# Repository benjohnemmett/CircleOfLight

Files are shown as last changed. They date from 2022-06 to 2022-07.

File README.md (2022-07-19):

# CircleOfLight
Hardware &amp; firmware files for a simple PCB light game.

The hardware files are a PCB design which includes 12 LED lights in a circle and 3 push buttons. It is driven by an atmega328p.

The firmware is a multimode setup with a main menu and up to 12 programs. Currently only 3 programs are implemented: Reflex Game, Countdown Timer, and Hardware Test.

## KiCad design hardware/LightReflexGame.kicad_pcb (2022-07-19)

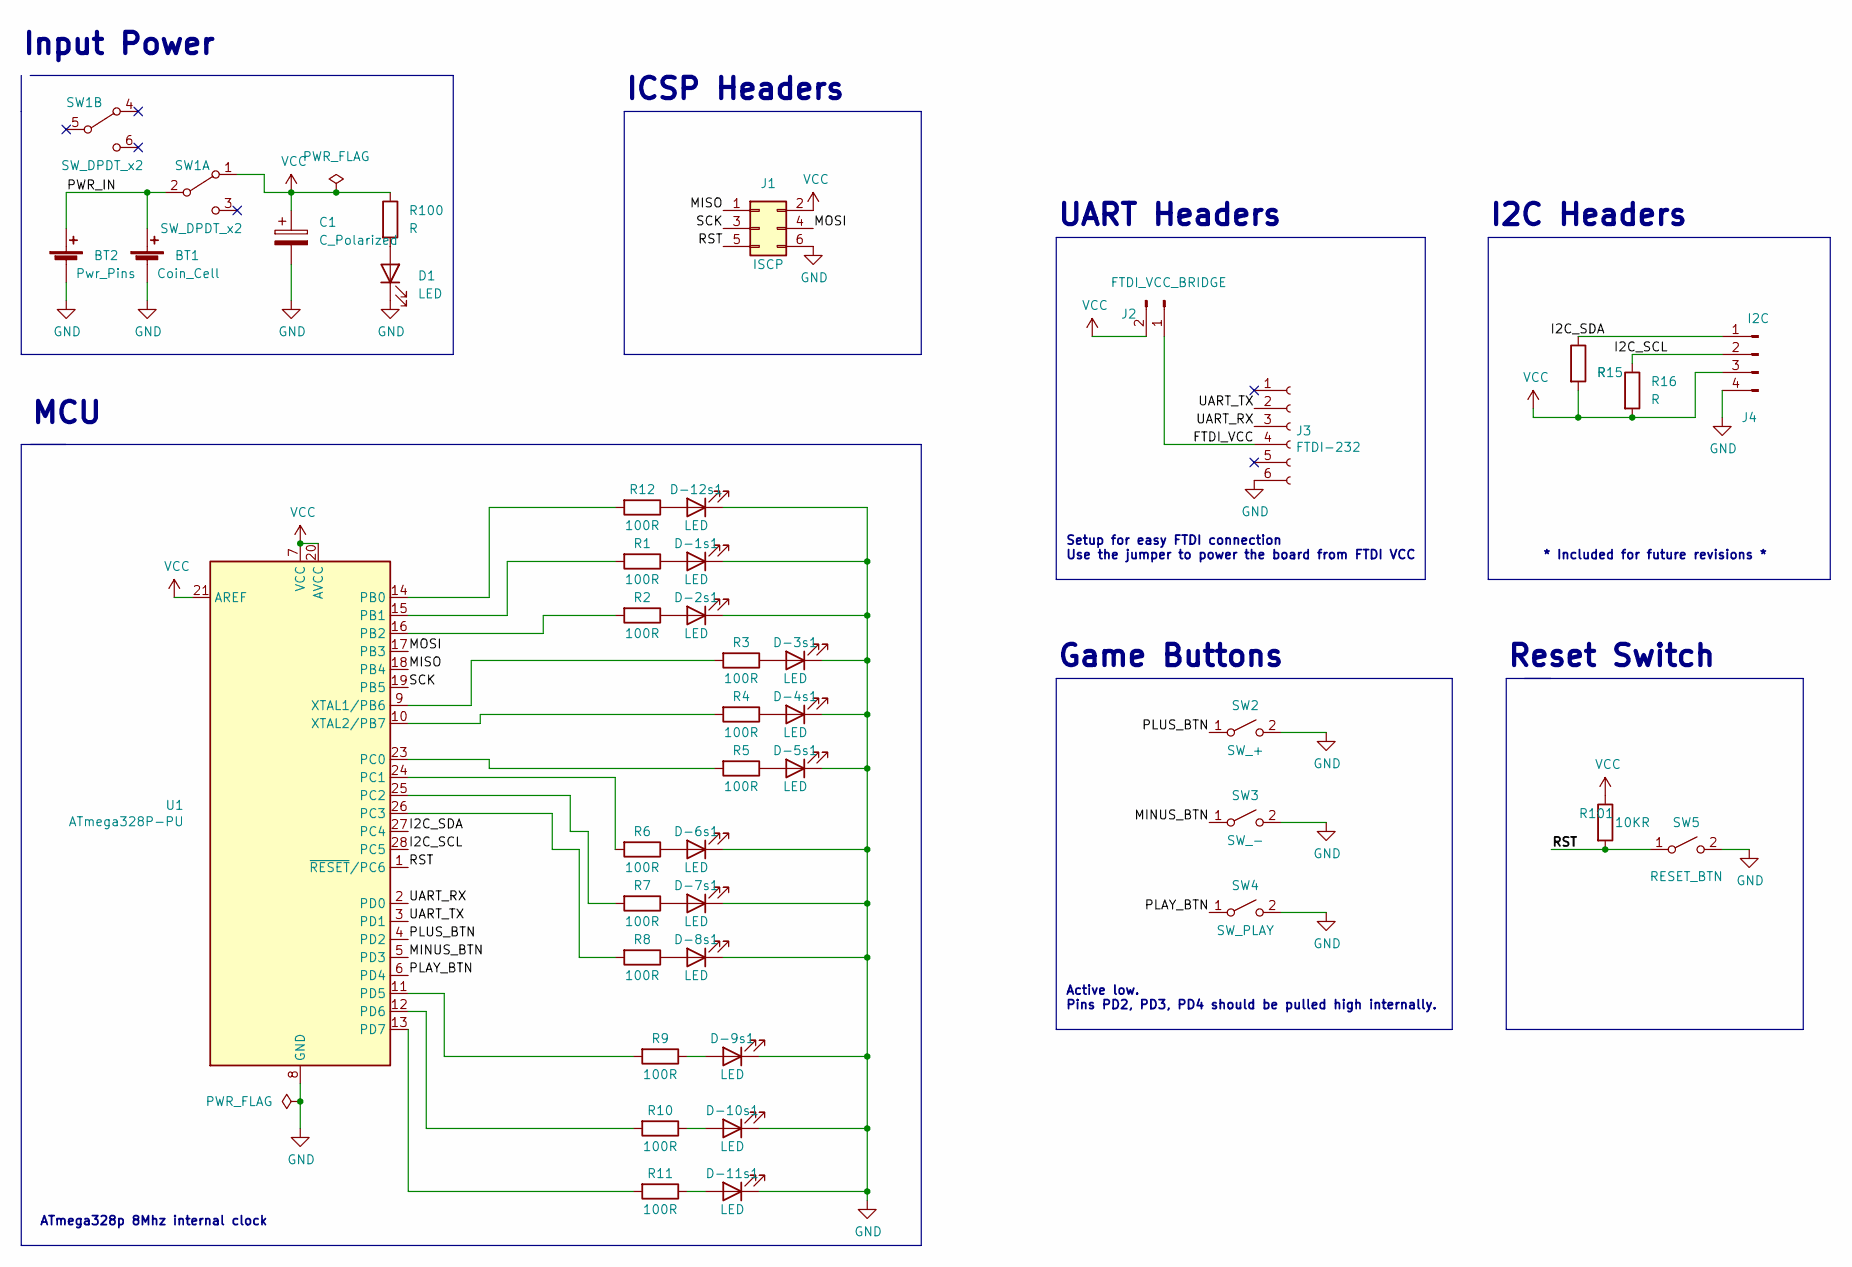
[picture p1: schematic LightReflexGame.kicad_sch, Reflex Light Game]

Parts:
BT1: Coin_Cell; BatteryHolder_bje_THT_1x2032
BT2: Pwr_Pins; PinHeader_1x02_P2.54mm_Vertical
C1: C_Polarized; CP_EIA-3528-12_Kemet-T
D1: LED; LED_0805_2012Metric
D-1s1, D-2s1, D-3s1, D-4s1, D-5s1, D-6s1, D-7s1, D-8s1, D-9s1, D-10s1, D-11s1, D-12s1: LED; LED_0805_2012Metric_Pad1.15x1.40mm_HandSolder
J1: ISCP; PinHeader_2x03_P2.54mm_Vertical
J2: FTDI_VCC_BRIDGE; PinHeader_1x02_P2.54mm_Vertical
J3: FTDI-232; PinHeader_1x06_P2.54mm_Vertical
J4: I2C; PinHeader_1x04_P2.54mm_Vertical
R1, R2, R3, R4, R5, R6, R7, R8, R9, R10, R11, R12: 100R; R_0805_2012Metric
R15, R16, R100: R; R_0805_2012Metric
R101: 10KR; R_0805_2012Metric
SW1: SW_DPDT_x2; SW_DPDT_MSS22D18_6pin_bje
SW2: SW_+; Switch_SPST_SMD_6mm_bje
SW3: SW_-; Switch_SPST_SMD_6mm_bje
SW4: SW_PLAY; Switch_SPST_SMD_6mm_bje
SW5: RESET_BTN; SW_SPST_FSMSM
U1: ATmega328P-PU; DIP-28_W7.62mm

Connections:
/FTDI_VCC: J2.1, J3.4
/I2C_SCL: J4.2, R16.1, U1.28 (PC5)
/I2C_SDA: J4.1, R15.1, U1.27 (PC4)
/MINUS_BTN: SW3.1 (A), U1.5 (PD3)
/MISO: J1.1, U1.18 (PB4)
/MOSI: J1.4, U1.17 (PB3)
/PLAY_BTN: SW4.1 (A), U1.6 (PD4)
/PLUS_BTN: SW2.1 (A), U1.4 (PD2)
/PWR_IN: BT1.1 (+), BT2.1 (+), SW1.2 (B); also elsewhere on the board
/RST: J1.5, R101.2, SW5.1 (A), U1.1 (~RESET/PC6)
/SCK: J1.3, U1.19 (PB5)
/UART_RX: J3.3, U1.2 (PD0)
/UART_TX: J3.2, U1.3 (PD1)
GND: BT1.2 (-), BT2.2 (-), C1.2, D1.1 (K), D-1s1.1 (K), D-2s1.1 (K), D-3s1.1 (K), D-4s1.1 (K), D-5s1.1 (K), D-6s1.1 (K), D-7s1.1 (K), D-8s1.1 (K), D-9s1.1 (K), D-10s1.1 (K), D-11s1.1 (K), D-12s1.1 (K), J1.6, J3.6, J4.4, SW2.2 (B), SW3.2 (B), SW4.2 (B), SW5.2 (B), U1.8 (GND), U1.22 (GND); also elsewhere on the board
unnamed: D1.2 (A), R100.2
unnamed: D-1s1.2 (A), R1.1
unnamed: D-2s1.2 (A), R2.1
unnamed: D-3s1.2 (A), R3.1
unnamed: D-4s1.2 (A), R4.1
unnamed: D-5s1.2 (A), R5.1
unnamed: D-6s1.2 (A), R6.1
unnamed: D-7s1.2 (A), R7.1
unnamed: D-8s1.2 (A), R8.1
unnamed: D-9s1.2 (A), R9.1
unnamed: D-10s1.2 (A), R10.1
unnamed: D-11s1.2 (A), R11.1
unnamed: D-12s1.2 (A), R12.1
unnamed: R1.2, U1.15 (PB1)
unnamed: R2.2, U1.16 (PB2)
unnamed: R3.2, U1.9 (XTAL1/PB6)
unnamed: R4.2, U1.10 (XTAL2/PB7)
unnamed: R5.2, U1.23 (PC0)
unnamed: R6.2, U1.24 (PC1)
unnamed: R7.2, U1.25 (PC2)
unnamed: R8.2, U1.26 (PC3)
unnamed: R9.2, U1.11 (PD5)
unnamed: R10.2, U1.12 (PD6)
unnamed: R11.2, U1.13 (PD7)
unnamed: R12.2, U1.14 (PB0)
VCC: C1.1, J1.2, J2.2, J4.3, R15.2, R16.2, R100.1, R101.1, SW1.1 (A), U1.7 (VCC), U1.20 (AVCC), U1.21 (AREF)

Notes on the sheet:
UART Headers
ICSP Headers
* Included for future revisions *
I2C Headers
ATmega328p 8Mhz internal clock
Reset Switch
Game Buttons
Setup for easy FTDI connection Use the jumper to power the board from FTDI VCC
MCU
Input Power
Active low. Pins PD2, PD3, PD4 should be pulled high internally.

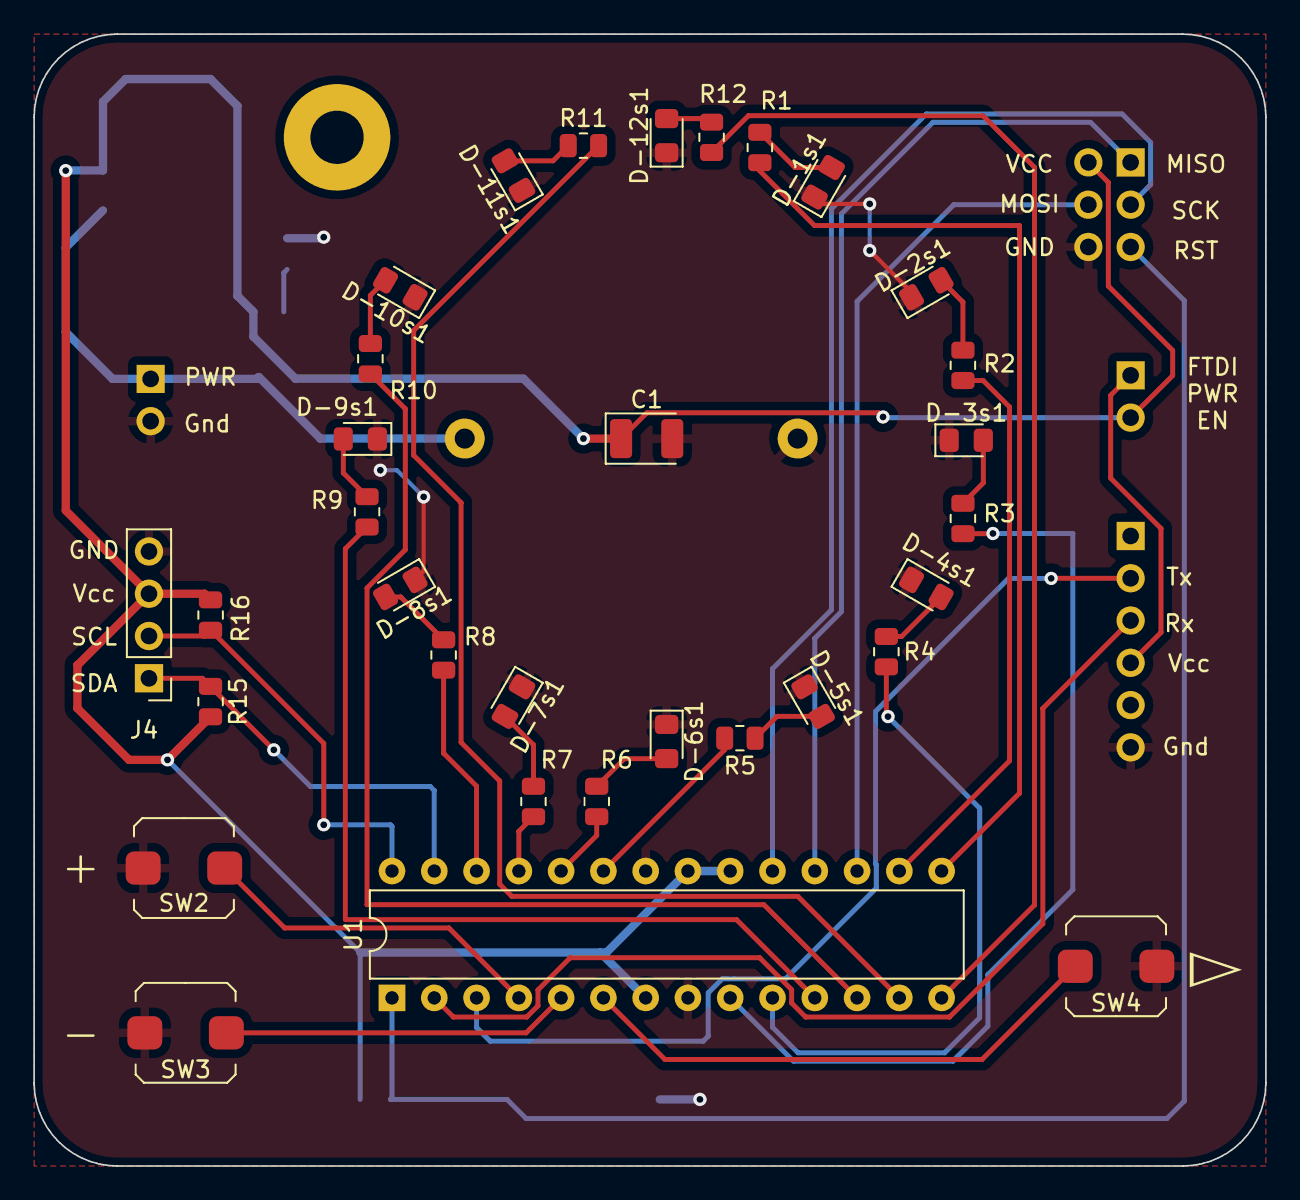
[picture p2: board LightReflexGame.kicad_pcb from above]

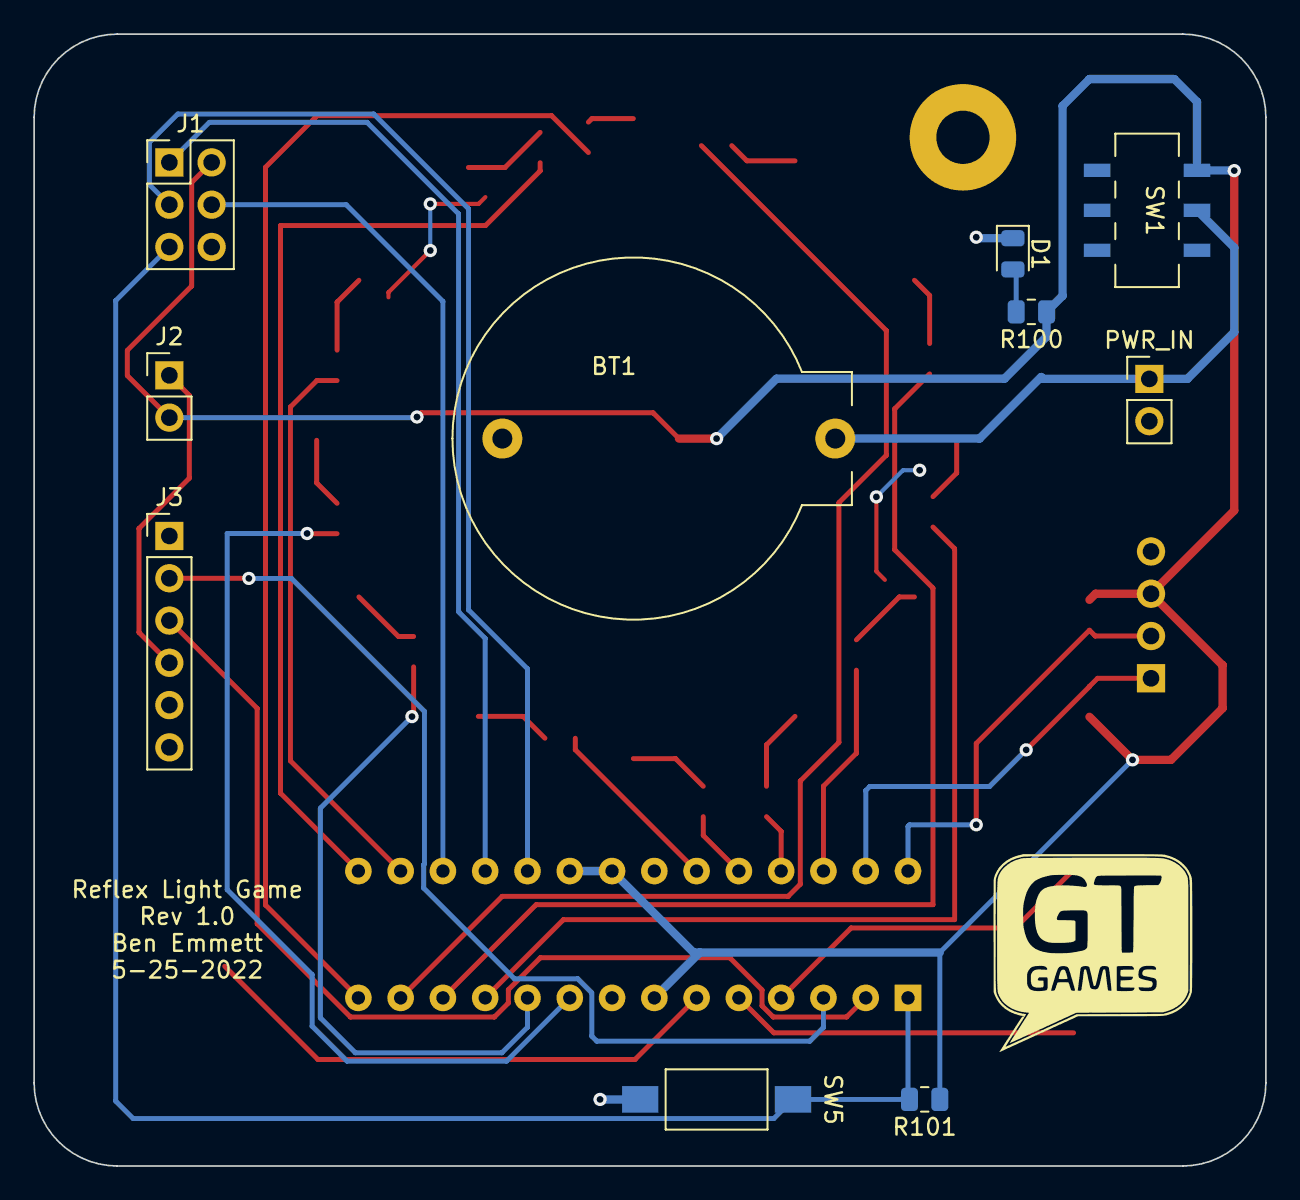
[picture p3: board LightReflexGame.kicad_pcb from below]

Board: 2 copper layers, 74.0 x 68.0 mm, 42 parts (10 on the bottom side), 40 nets.

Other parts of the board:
PWR_IN: Pwr_Pins; PinHeader_1x02_P2.54mm_Vertical

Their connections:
/PWR_IN: PWR_IN.1 (+); also elsewhere on the board
GND: PWR_IN.2 (-); also elsewhere on the board

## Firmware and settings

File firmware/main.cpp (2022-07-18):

#include <util/delay.h>
#include "uart.h"
#include "LightController.h"
#include "ReflexProgram.h"
#include "ButtonManager.h"
#include "MenuProgram.h"
#include "TestProgram.h"
#include "CountDownTimerProgram.h"

#define TICKS_TO_FORCE_EXIT 2000

ButtonManager buttonManager;
LightController lightController;
TestProgram testProgram(&lightController, &buttonManager);
ReflexProgram reflexProgram(&lightController, &buttonManager);
CountDownTimerProgram countdownTimerProgram(&lightController, &buttonManager);

IProgram *runningProgram;

MenuProgram menuProgram(&lightController, &buttonManager, &runningProgram);

int main() {
    SetupUart();
    EnableUartTransmission();

    SendStringToUart((char*)"Adding programs to menu\r\n");
    menuProgram.AddProgram(&reflexProgram);
    menuProgram.AddProgram(&countdownTimerProgram);
    menuProgram.AddProgram(&testProgram);

    SendStringToUart((char*)"Setting up menu program\r\n");
    runningProgram = &menuProgram;
    runningProgram->SetupProgram();

    SendStringToUart((char*)"Entering loop\r\n");
    while (1) {
        buttonManager.Update();
        runningProgram->Update();

        bool force_exit = buttonManager.GetMinusButtonHoldTicks() > TICKS_TO_FORCE_EXIT &&
                        runningProgram != &menuProgram;

        if (runningProgram->IsDoneRunning() || force_exit) {
            runningProgram->TearDownProgram();
            runningProgram = &menuProgram;
            runningProgram->SetupProgram();
        }

        _delay_ms(1);
    }
}

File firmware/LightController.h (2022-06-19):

#ifndef __LIGHT_CONTROLLER_H__
#define __LIGHT_CONTROLLER_H__

#include <avr/io.h>

#define LIGHT_01_PORT PORTB
#define LIGHT_02_PORT PORTB
#define LIGHT_03_PORT PORTB
#define LIGHT_04_PORT PORTB
#define LIGHT_05_PORT PORTC
#define LIGHT_06_PORT PORTC
#define LIGHT_07_PORT PORTC
#define LIGHT_08_PORT PORTC
#define LIGHT_09_PORT PORTD
#define LIGHT_10_PORT PORTD
#define LIGHT_11_PORT PORTD
#define LIGHT_12_PORT PORTB

#define LIGHT_01_DDR DDRB
#define LIGHT_02_DDR DDRB
#define LIGHT_03_DDR DDRB
#define LIGHT_04_DDR DDRB
#define LIGHT_05_DDR DDRC
#define LIGHT_06_DDR DDRC
#define LIGHT_07_DDR DDRC
#define LIGHT_08_DDR DDRC
#define LIGHT_09_DDR DDRD
#define LIGHT_10_DDR DDRD
#define LIGHT_11_DDR DDRD
#define LIGHT_12_DDR DDRB

#define LIGHT_01_PIN PB1
#define LIGHT_02_PIN PB2

#define LIGHT_03_PIN PB6
#define LIGHT_04_PIN PB7
#define LIGHT_05_PIN PC0
#define LIGHT_06_PIN PC1
#define LIGHT_07_PIN PC2
#define LIGHT_08_PIN PC3
#define LIGHT_09_PIN PD5
#define LIGHT_10_PIN PD6
#define LIGHT_11_PIN PD7
#define LIGHT_12_PIN PB0

class LightController {
    public:
        void SetupLights();
        void SetLightValue(uint8_t index, uint8_t value);
        void ClearAllLights();
};

#endif

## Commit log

2022-06-02 Initial commit. Simple blink & uart test code implemented.
2022-06-16 Lights & buttons test working.
2022-06-17 Restructerd code into separate classes LightController, ButtonManager, ReflexProgram. Functionally the same as before.
2022-06-19 Added support for button release delegate methods.
2022-06-21 Added force quit program with 2 sec minus button hold.
2022-07-18 Finished countdown timer program.
2022-07-19 Adding PCB files.
    [LightReflexGame.kicad_pcb, LightReflexGame.kicad_sch]
